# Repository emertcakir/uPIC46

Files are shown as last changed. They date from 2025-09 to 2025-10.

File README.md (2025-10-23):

# uPIC46
EMC

uPIC46 Development Board

The uPIC46 is a development board designed around the Microchip PIC18F46K22-I/PT microcontroller.  
It is intended for hobbyists, students, and professionals who want a versatile platform for learning, prototyping, and industrial communication testing.

----------------------------------------------------
✨ Features
----------------------------------------------------
- MCU: PIC18F46K22-I/PT (TQFP package)
- Clocking: External crystal oscillator support
- Memory Expansion: Onboard 24LC256 I²C EEPROM
- RTC: DS3231MZ real-time clock
- USB-UART Bridge: For programming and PC communication
- Connectivity:
  * UART, SPI, I²C headers exposed
  * RTS/CTS and other flow-control pins available on headers
  * RS-485 transceiver for half-duplex communication
  * CAN Bus interface via MCP2515 + SN65HVD230
- Reset & Indicators:
  * Reset push button
  * User indicator LEDs
- Headers:
  * Clearly labeled header pins (A1, A2, A3…) with silkscreen reference table on PCB
  * Breakout headers for easy access to MCU I/O pins

----------------------------------------------------
🛠 Hardware Design
----------------------------------------------------
- Compact and user-friendly layout
- Industrial interfaces: CAN and RS-485 included
- Silkscreen pinout table on PCB for quick reference
----------------------------------------------------
📸 Images
----------------------------------------------------
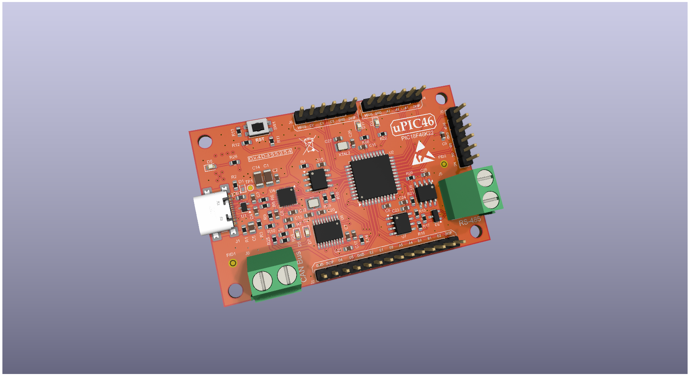
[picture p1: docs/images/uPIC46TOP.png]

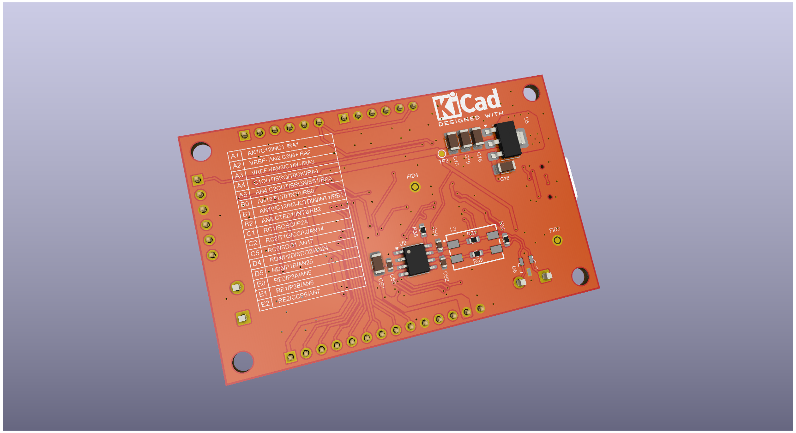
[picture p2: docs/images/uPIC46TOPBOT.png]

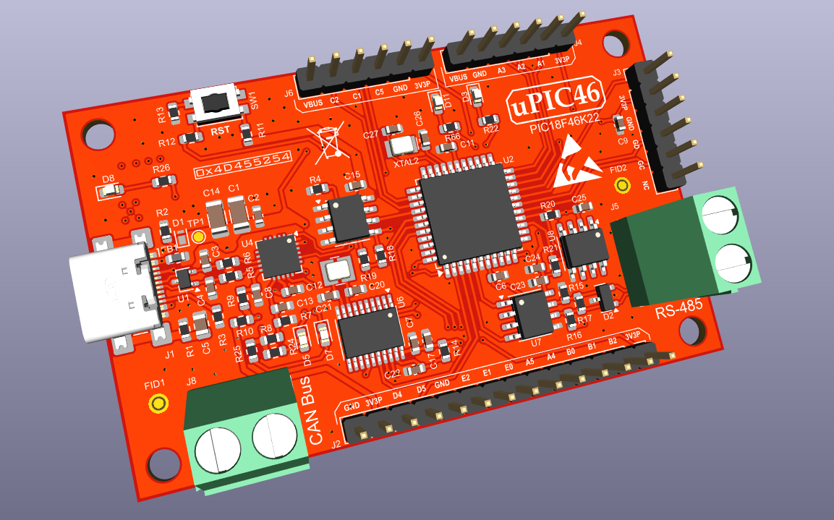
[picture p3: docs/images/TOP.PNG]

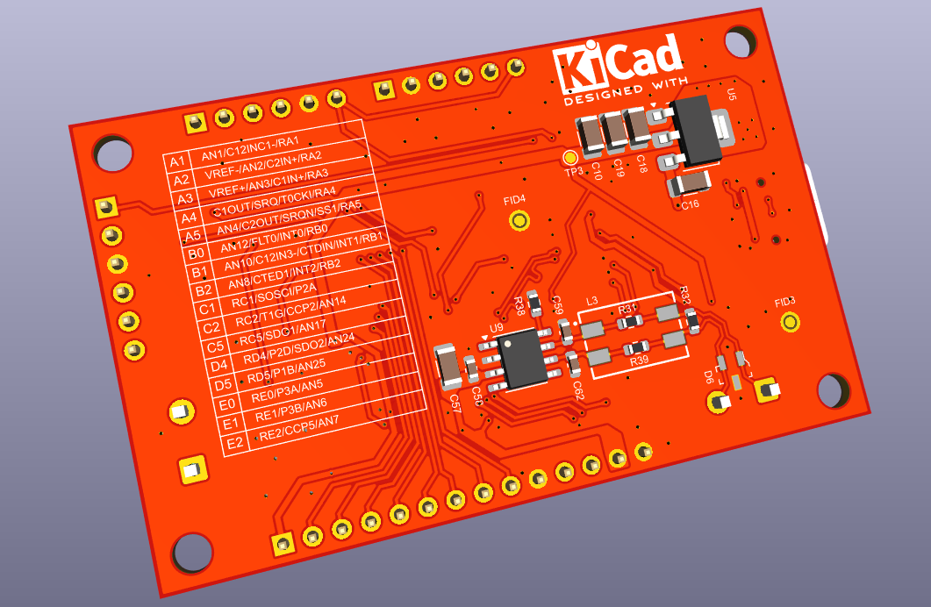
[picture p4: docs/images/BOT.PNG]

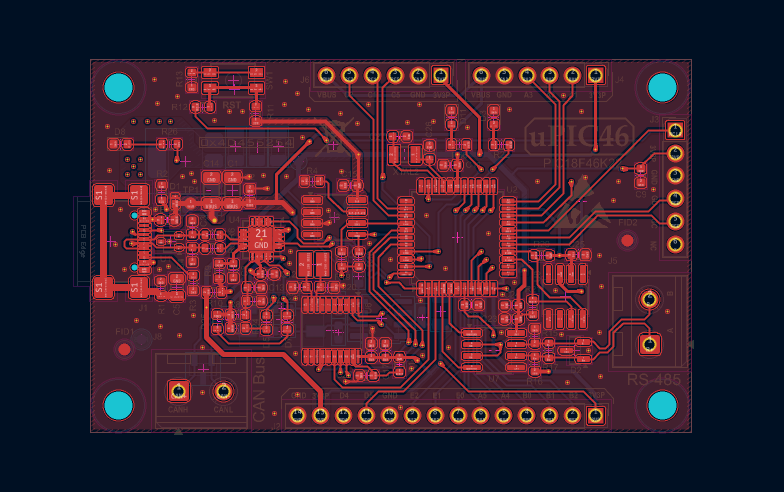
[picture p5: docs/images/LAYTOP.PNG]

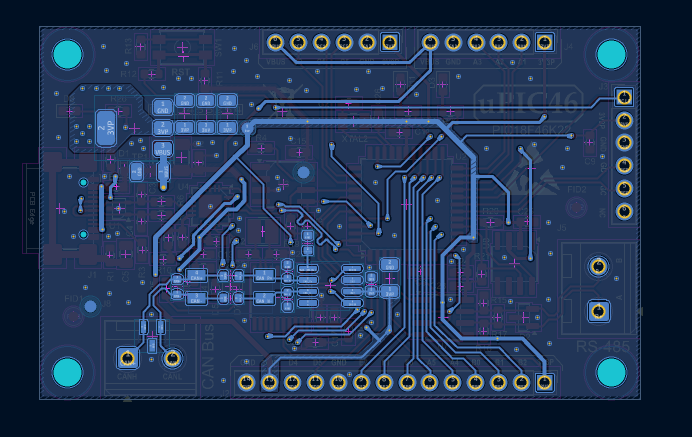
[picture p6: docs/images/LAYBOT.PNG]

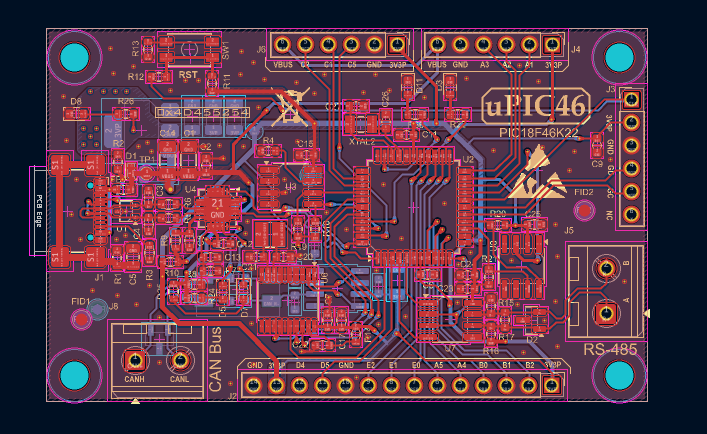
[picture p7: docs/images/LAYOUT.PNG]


----------------------------------------------------
📜 License
----------------------------------------------------
This project is open-source. You are free to use, modify, and distribute it under the terms of the MIT License.

CRITICAL WARNING: This PCB design is currently an experimental, unverified prototype (AS-IS). I have not yet manufactured or functionally tested this version. Proceeding with production carries a high risk of failure and is undertaken solely at your own risk.

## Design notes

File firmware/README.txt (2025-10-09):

uPIC46 Example Firmware Collection

This archive contains simple example projects for the uPIC46 development board (PIC18F46K22).
Each example is self-contained (single-file main.c) and intended to be imported into MPLAB X (XC8).
Adjust configuration bits in MPLAB X Project -> Configuration Bits before programming the device.

Assumptions used in the examples:
- MCU clock: external 8 MHz crystal (update _XTAL_FREQ if different)
- LED1 -> RC0
- LED2 -> RD3
- UART1 TX -> RC6 (EUSART TX)
- UART1 RX -> RC7 (EUSART RX)
- I2C (bit-banged) SDA -> RB4, SCL -> RB5
- SPI (bit-banged for MCP2515) SCK -> RD0, MOSI -> RD4, MISO -> RD1, CS -> RD2
- RS485 DE (if used) -> RB3

These examples are for demonstration and testing; they are not production-ready drivers.

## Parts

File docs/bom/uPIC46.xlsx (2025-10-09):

 |  | uPIC46 Development Board
Reference | Qty | Value | MPN | Footprint | Description
C1,C10,C19 | 3 | - | CGA5L2X7R1E105K160AA | Capacitor_SMD:C_1206_3216Metric | Unpolarized capacitor
C2,C6,C7,C8,C9,C11,C12,C15,C17,C22,C23,C24,C25,C58 | 14 | - | CC0603KRX7R8BB104 | Capacitor_SMD:C_0603_1608Metric | Unpolarized capacitor
C3,C4 | 2 | - | 0603YC470KAT2A | Capacitor_SMD:C_0603_1608Metric | Unpolarized capacitor
C5 | 1 | - | CC0805KRX7R9BB222 | Capacitor_SMD:C_0805_2012Metric | Unpolarized capacitor
C13 | 1 | - | KGM15AR51E103KT | Capacitor_SMD:C_0603_1608Metric | Unpolarized capacitor
C14 | 1 | - | CL31B475KAHNFNE | Capacitor_SMD:C_1206_3216Metric | Unpolarized capacitor
C16,C18,C57 | 3 | - | CL31B106KAHNNNE | Capacitor_SMD:C_1206_3216Metric | Unpolarized capacitor
C20,C21,C26,C27 | 4 | - | CC0603KRNPO9BN120 | Capacitor_SMD:C_0603_1608Metric | Unpolarized capacitor
C59,C62 | 2 | - | KGM15AR71E101MT | Capacitor_SMD:C_0603_1608Metric | Unpolarized capacitor
D1 | 1 | - | PTVS5V0Z1USKYL | Diode_SMD:Nexperia_DSN1608-2_1.6x0.8mm | 5V, 1200W TVS unidirectional diode, DSN1608-2
D2 | 1 | - | SM712-02HTG | Package_TO_SOT_SMD:SOT-23 | 7V/12V, 600W Asymmetrical TVS Diode Array, SOT-23
D3,D5,D7,D8,D11 | 5 | - | 150060RS75000 | LED_SMD:LED_0603_1608Metric | Light emitting diode
D6 | 1 | - | PESD1CAN,215 | digikey-footprints:SOT-23-3 | TVS DIODE 24V 70V SOT23
FB1 | 1 | - | BLM18AG601BH1D | Inductor_SMD:L_0603_1608Metric | Ferrite bead
J1 | 1 | - | USB4110-GF-A | Connector_USB:USB_C_Receptacle_GCT_USB4110 | USB 2.0-only 16P Type-C Receptacle connector
J2 | 1 | Conn_01x14_Socket | HEADER | Connector_PinHeader_2.54mm:PinHeader_1x14_P2.54mm_Vertical | Generic connector, single row, 01x14, script generated
J3 | 1 | Conn_PIC_ICSP_ICD | HEADER | Connector_PinHeader_2.54mm:PinHeader_1x06_P2.54mm_Vertical | Microchip PIC In-Circuit Serial Programming/Debugging (ICSP/ICD) connector
J4,J6 | 2 | Conn_01x06_Socket | HEADER | Connector_PinHeader_2.54mm:PinHeader_1x06_P2.54mm_Vertical | Generic connector, single row, 01x06, script generated
J5,J8 | 2 | - | RND 205-00045 | TerminalBlock_RND:TerminalBlock_RND_205-00045_1x02_P5.00mm_Horizontal | Generic screw terminal, single row, 01x02, script generated (kicad-library-utils/schlib/autogen/connector/)
R1,R12 | 2 | - | ERJ-3EKF1000V | Resistor_SMD:R_0603_1608Metric | Resistor
R2,R3,R4 | 3 | - | RC0603FR-075K1L | Resistor_SMD:R_0603_1608Metric | Resistor
R5,R6,R9,R10,R13,R31,R38,R39 | 8 | - | RC0603JR-070RL | Resistor_SMD:R_0603_1608Metric | Resistor
R7 | 1 | - | ERA-3AEB153V | Resistor_SMD:R_0603_1608Metric | Resistor
R8,R11,R14,R15,R16,R18,R19,R20,R21 | 9 | - | RC0603FR-0710KL | Resistor_SMD:R_0603_1608Metric | Resistor
R17,R32 | 2 | - | ERA-3AEB121V | Resistor_SMD:R_0603_1608Metric | Resistor
R22,R24,R25,R26,R66 | 5 | - | ERA-3AEB102V | Resistor_SMD:R_0603_1608Metric | Resistor
SW1 | 1 | - | EVQ-P2202W | Button_Switch_SMD:SW_SPST_EVQP2 | Push button switch, generic, two pins
U1 | 1 | - | TPD2E2U06DCK | Package_TO_SOT_SMD:SOT-323_SC-70 | Dual-Channel High-Speed ESD Protection, SC-70
U2 | 1 | - | PIC18F46K22-I/PT | Package_QFP:TQFP-44_10x10mm_P0.8mm | 64K Flash, 3.5K RAM, 1K EEPROM PIC18 Microcontroller ADC PWM SPI I2C USART in TQFP44 package
U3 | 1 | - | 24LC256 | Package_SO:SOIC-8_3.9x4.9mm_P1.27mm | I2C Serial EEPROM, 256Kb, DIP-8/SOIC-8/TSSOP-8/DFN-8
U4 | 1 | - | FT231XQ-R | Package_DFN_QFN:QFN-20-1EP_4x4mm_P0.5mm_EP2.5x2.5mm | Full Speed USB to Full Handshake UART, QFN-20
U5 | 1 | - | AMS1117-3.3 | Package_TO_SOT_SMD:SOT-223-3_TabPin2 | 1A Low Dropout regulator, positive, 3.3V fixed output, SOT-223
U6 | 1 | - | MCP2515-Xst | Package_SO:TSSOP-20_4.4x6.5mm_P0.65mm | Stand-Alone CAN Controller with SPI Interface, TSSOP-20
U7 | 1 | - | MAX3485CSA+T | Package_SO:SOIC-8_3.9x4.9mm_P1.27mm | True RS-485/RS-422, 10Mbps, Slew-Rate Limited, with low-power shutdown, with receiver/driver enable, 32 receiver drive capacitity, DIP-8 and SOIC-8
U8 | 1 | - | DS3231MZ | Package_SO:SOIC-8_3.9x4.9mm_P1.27mm | Â±5ppm, I2C Real-Time Clock SOIC-8
U9 | 1 | - | SN65HVD230 | Package_SO:SOIC-8_3.9x4.9mm_P1.27mm | CAN Bus Transceivers, 3.3V, 1Mbps, Low-Power capabilities, SOIC-8
XTAL1 | 1 | - | NX3225GD-8MHZ-STD-CRA-3 | digikey-footprints:SMD-2_3.2x2.5mm | CRYSTAL 8.0000MHZ 8PF SMD
XTAL2 | 1 | - | ECS-.327-12.5-34B-TR | digikey-footprints:SMD-2_3.2x1.5mm | CRYSTAL 32.7680KHZ 12.5PF SMD

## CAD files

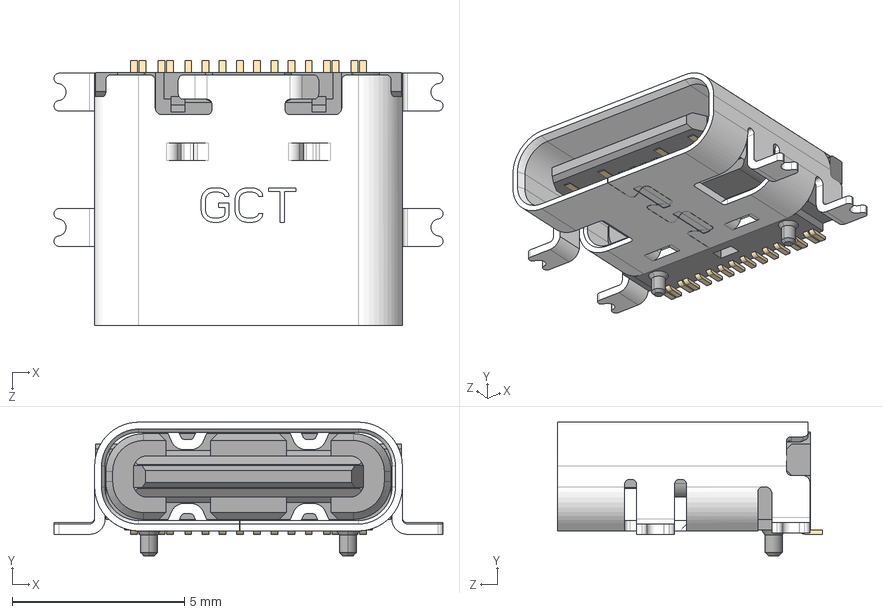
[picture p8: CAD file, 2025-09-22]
hardware/3D/USB4110GFA--3DModel-STEP-269445.STEP
11.3 x 3.89 x 7.70 mm

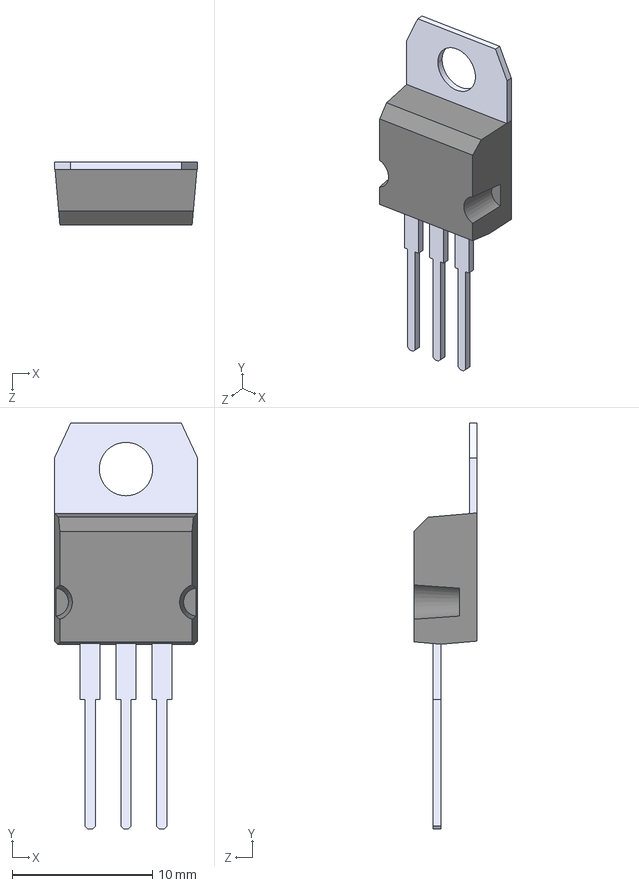
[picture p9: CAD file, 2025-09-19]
hardware/3D/L7805CV.STEP
10.2 x 28.9 x 4.50 mm

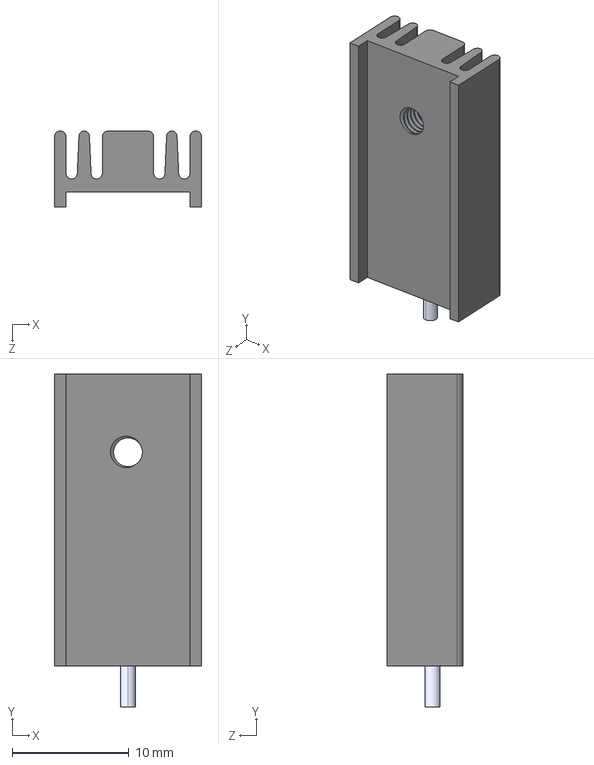
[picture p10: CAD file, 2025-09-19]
hardware/3D/SK 95 25 STS TO 220--3DModel-STEP-269445.STEP
12.6 x 28.5 x 6.50 mm

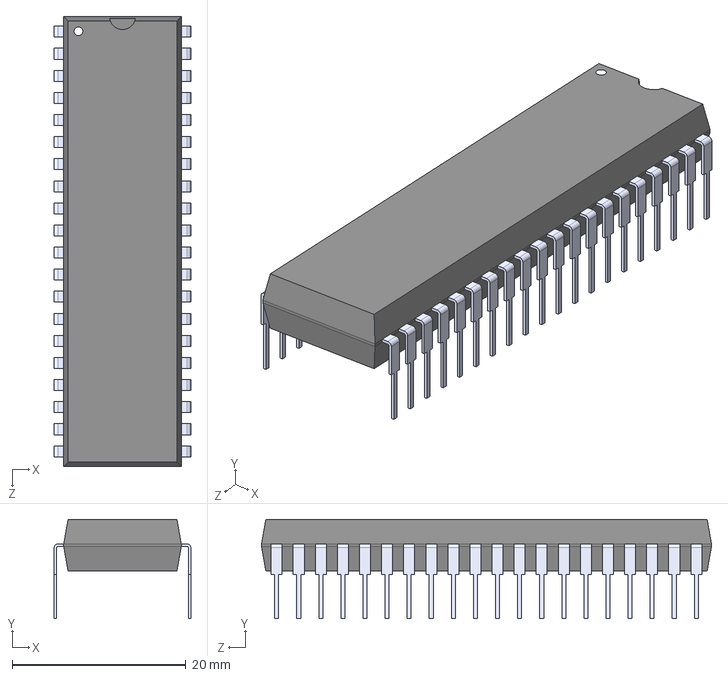
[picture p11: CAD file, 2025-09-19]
hardware/3D/PIC18F46K22-I_P.step
15.7 x 11.4 x 51.8 mm

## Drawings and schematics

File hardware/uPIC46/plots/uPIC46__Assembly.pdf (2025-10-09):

B.Paste F.Cu | | | 1.51 mm | 1 B.Cu

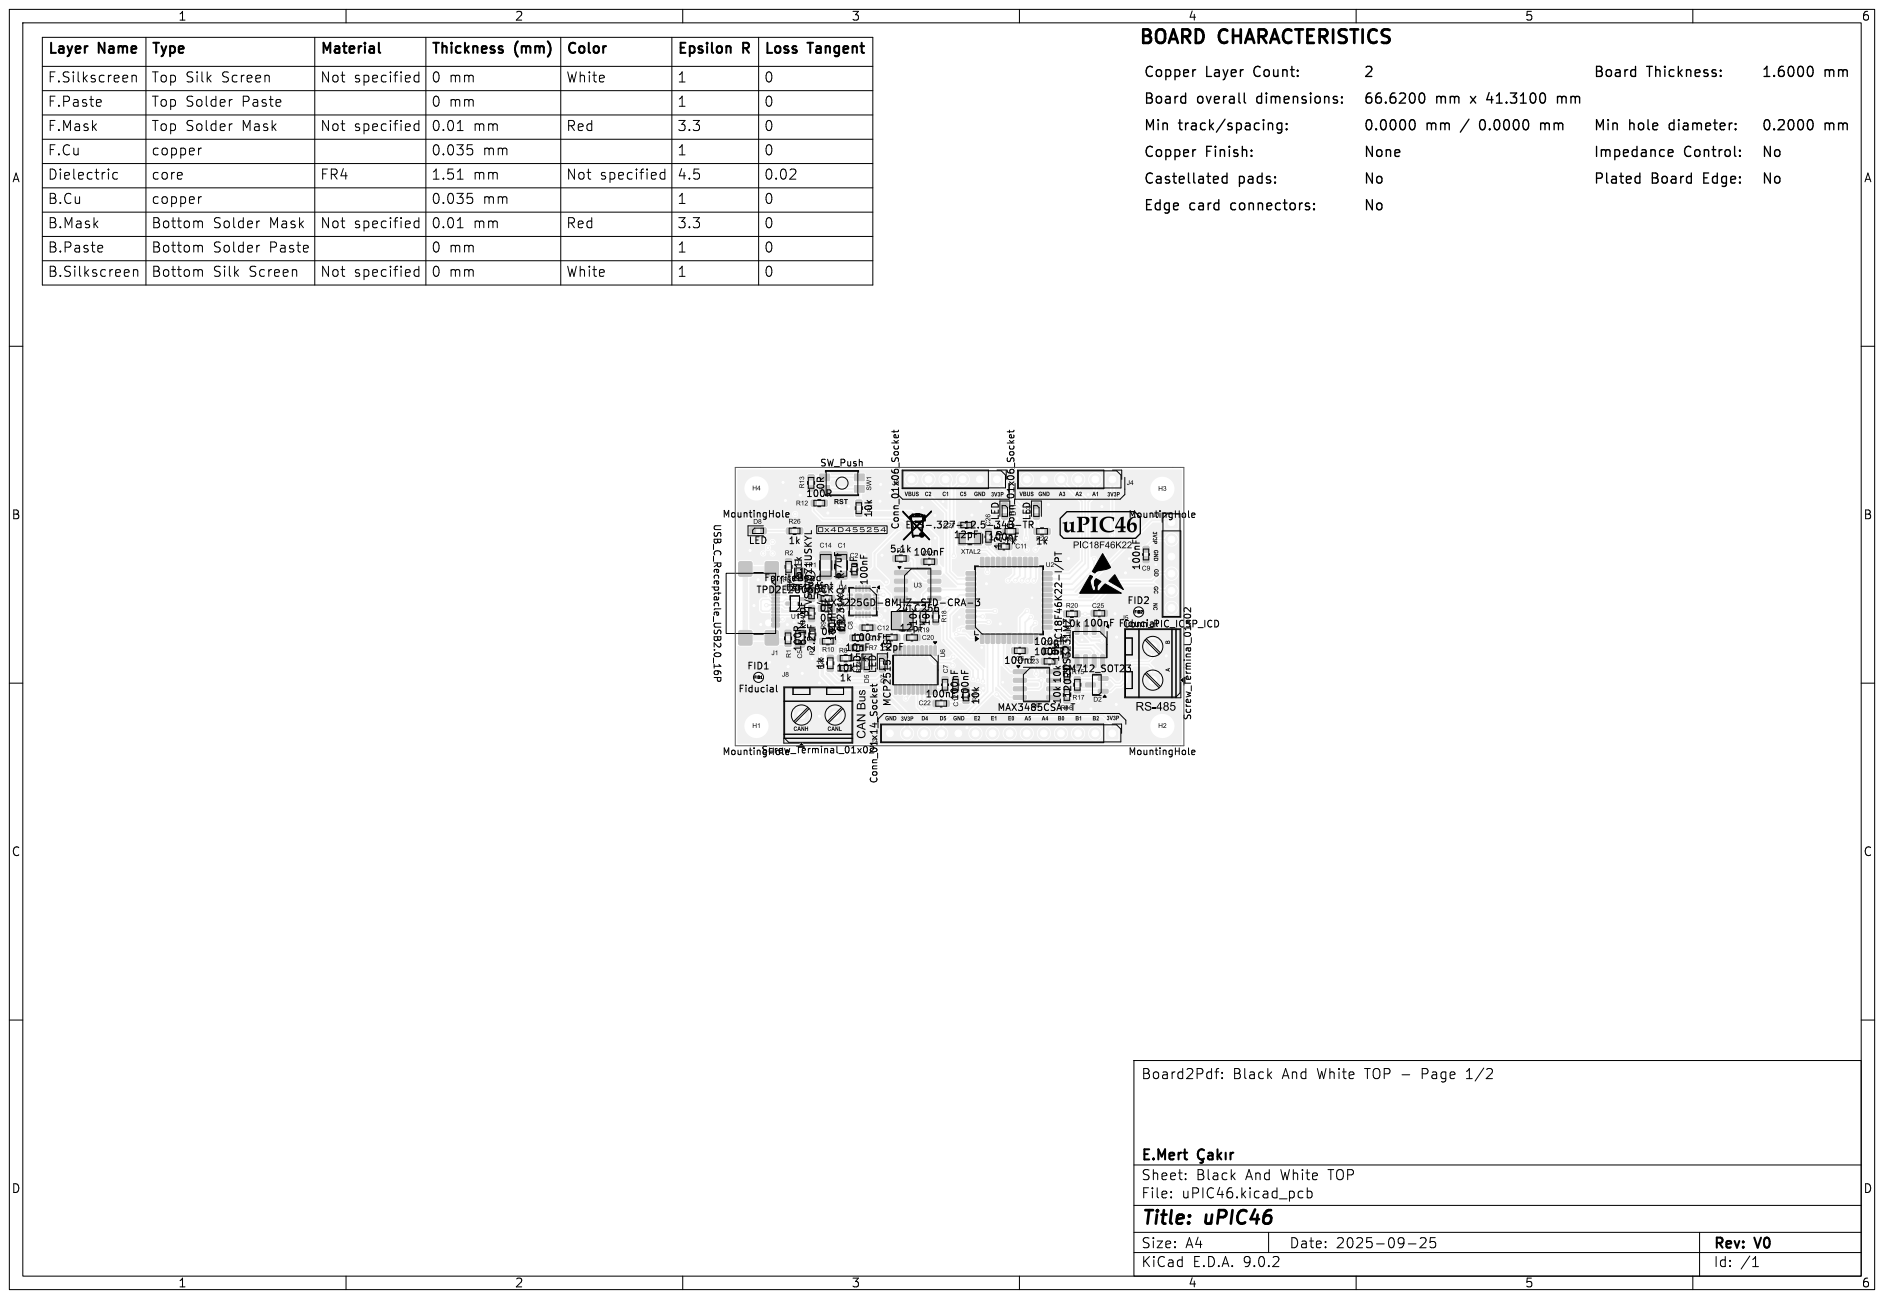
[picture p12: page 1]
FID1; FID2; D Date: 2025-09-25 KiCad; E.D.A. 9.0.2 Size: A4; Rev: V0; Id: /1 Title: uPIC46; File: uPIC46.kicad_pcb Sheet: Black; And; White; TOP; E.Mert þÿÇak1r Board2Pdf:; Black; TOP -; Page; Copper; Finish: 1; 1 Red; Plated; Board; Edge: copper; Thickness: 0 Top Solder Paste; Castellated; pads: 0 mm; Impedance; Control: Edge card; connectors:; Board overall; dimensions: Top Silk Screen; Not specified; Min track/spacing:; Loss Tangent F.Silkscreen; Bottom Solder Mask; core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

(mm) 0 mm | Not specified Thickness White | 1 | Copper Layer Count: F.Paste

Layer Name B.Silkscreen | Top Solder Mask | Material | 0 mm 0.01 mm | 0 Type F.Mask 0 Bottom Solder Paste 0

Epsilon R

0 Not specified

No Not specified

Screen | FR4 | 0.035 mm | 1 B.Mask Dielectric | 0.02 Bottom Silk

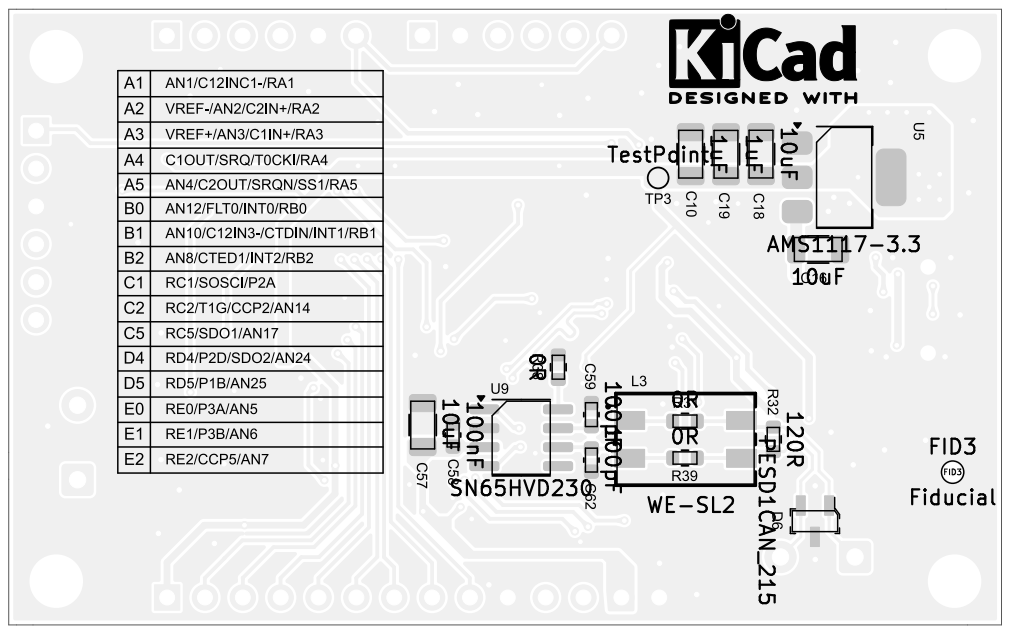
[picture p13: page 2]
FID3; D Date: 2025-09-25 KiCad; E.D.A. 9.0.2 Size: A4; Rev: V0; Id: /1 Title: uPIC46; File: uPIC46.kicad_pcb Sheet: Black; And; White; BOT E.Mert þÿÇak1r Board2Pdf:; Black; BOT -; Page 2/2; Fiducial FID3 WE-SL2 ¹⁰uF; 10uF 1uFTestPoint; SN65HVD230; AMS1117-3.3 ¹uF PESD1CAN_215 0R

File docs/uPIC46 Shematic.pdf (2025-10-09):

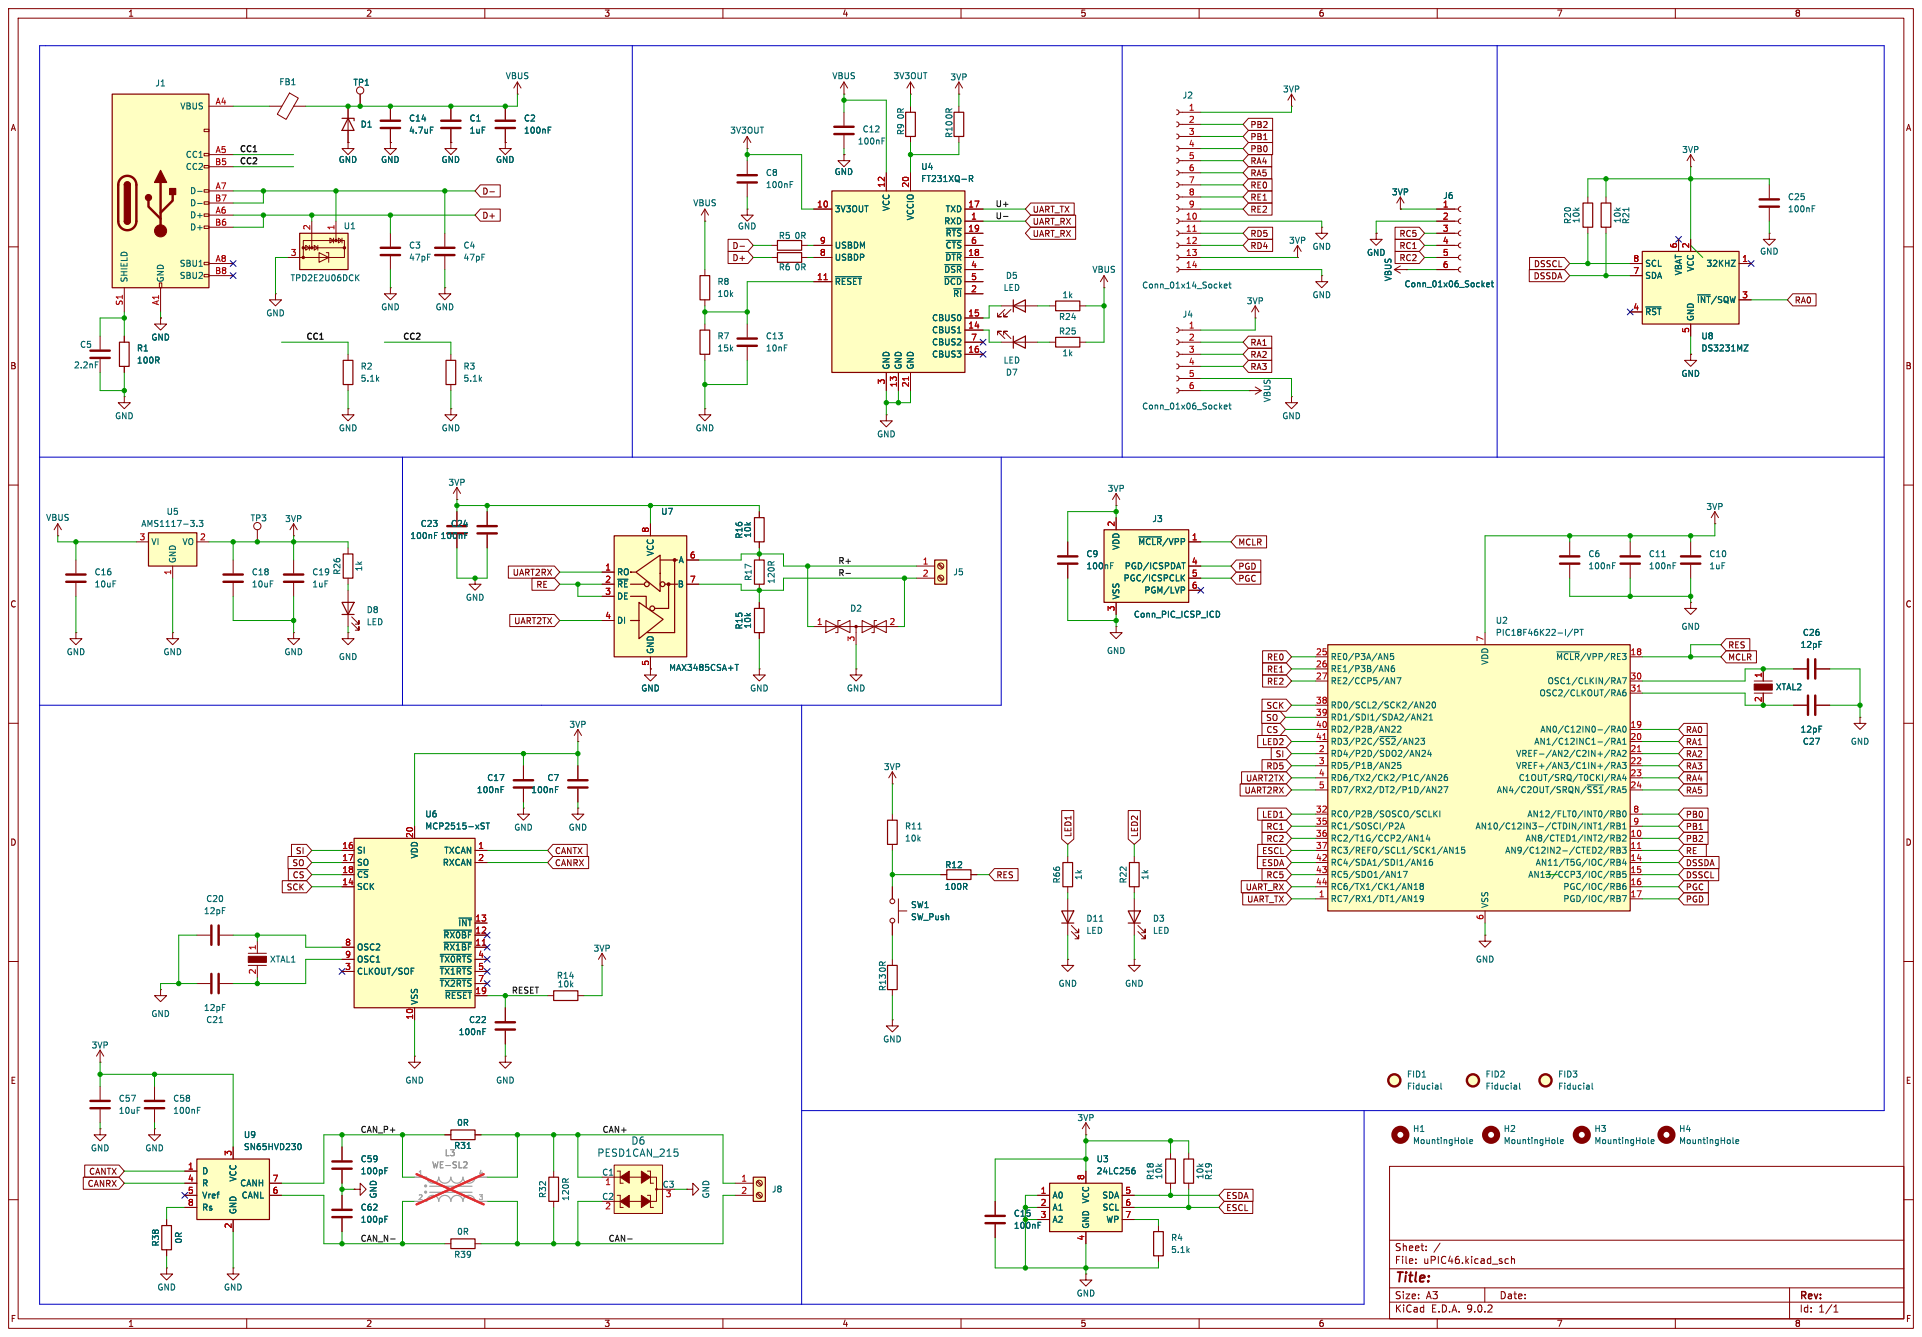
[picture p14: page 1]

3 GND 13 VCCIO 20 GND 21 TXD 17 RXD 1 ~{RTS}19 ~{CTS}6 ~{DTR}18 ~{DSR}4 ~{DCD}5 ~{RI}2 CBUS0 15 CBUS1 14 CBUS2 7 CBUS3 16 U4 FT231XQ-R GND

3 GND 13 VCCIO 20 GND 21 TXD 17 RXD 1 ~{RTS}19 ~{CTS}6 ~{DTR}18 ~{DSR}4 ~{DCD}5 ~{RI}2 CBUS0 15 CBUS1 14 CBUS2 7 CBUS3 16 GND

3 ~{MCLR}/VPP1 PGD/ICSPDAT 4 PGC/ICSPCLK 5 PGM/LVP 6 R12

3 ~{MCLR}/VPP1 PGD/ICSPDAT 4 PGC/ICSPCLK 5 PGM/LVP 6

6 ~{MCLR}/VPP/RE3 18 OSC1/CLKIN/RA7 30 OSC2/CLKOUT/RA6 31 AN0/C12IN0-/RA0 19 AN1/C12INC1-/RA1 20 VREF-/AN2/C2IN+/RA2 21 VREF+/AN3/C1IN+/RA3 22 C1OUT/SRQ/T0CKI/RA4 23 AN4/C2OUT/SRQN/~{SS1}/RA5 24 AN12/FLT0/INT0/RB0 8 AN10/C12IN3-/CTDIN/INT1/RB1 9 AN8/CTED1/INT2/RB2 10 AN9/C12IN2-/CTED2/RB3 11 AN11/T5G/IOC/RB4 14 AN13/CCP3/IOC/RB5 15 PGC/IOC/RB6 16 PGD/IOC/RB7 17 U2PIC18F46K22-I/PT

2 CANH 7 CANL 6 U6 MCP2515-xST SI 16 SO 17 ~{CS} 18 SCK 14 OSC2 8 OSC1 9 CLKOUT/SOF 3 VDD 20 VSS 10 TXCAN 1 RXCAN 2 ~{INT} 13 ~{RX0BF}12 ~{RX1BF}11 ~{TX0RTS}4 ~{TX1RTS}5 ~{TX2RTS}7 ~{RESET} 19 C17

Id: 1/1 Title: File: uPIC46.kicad_sch Sheet: /

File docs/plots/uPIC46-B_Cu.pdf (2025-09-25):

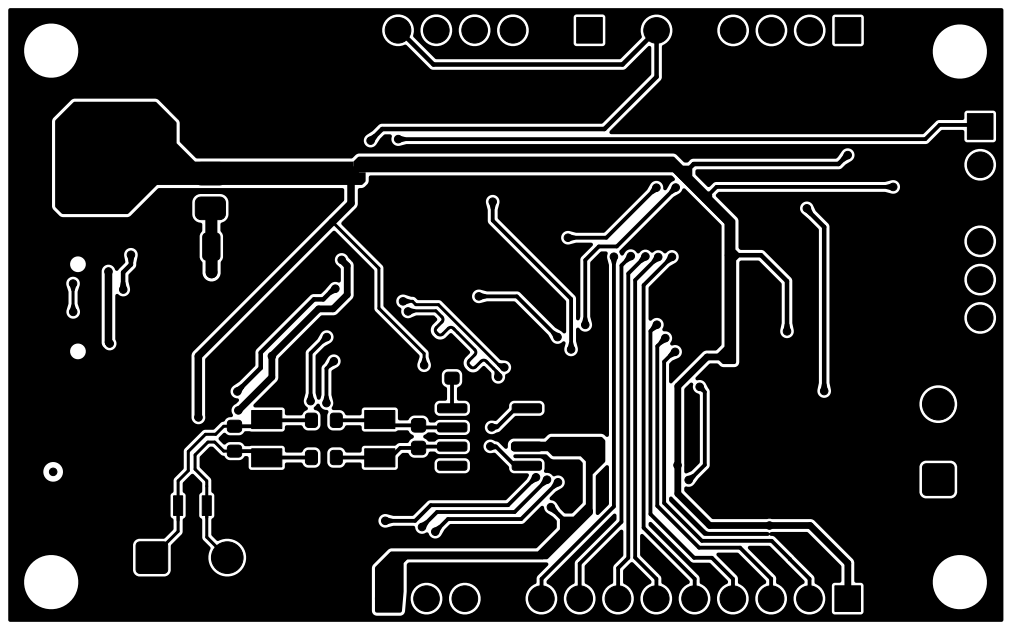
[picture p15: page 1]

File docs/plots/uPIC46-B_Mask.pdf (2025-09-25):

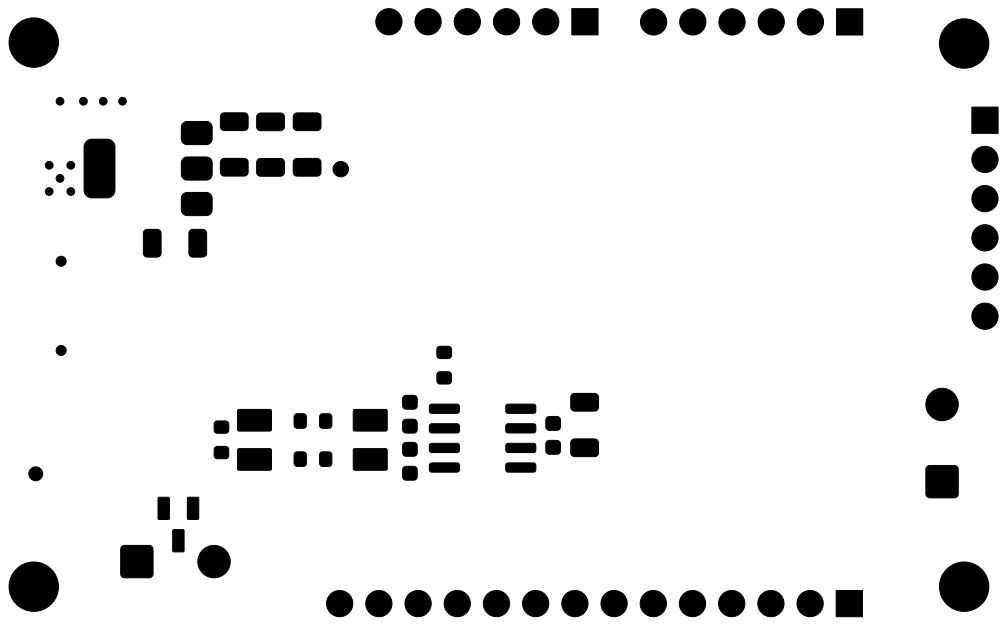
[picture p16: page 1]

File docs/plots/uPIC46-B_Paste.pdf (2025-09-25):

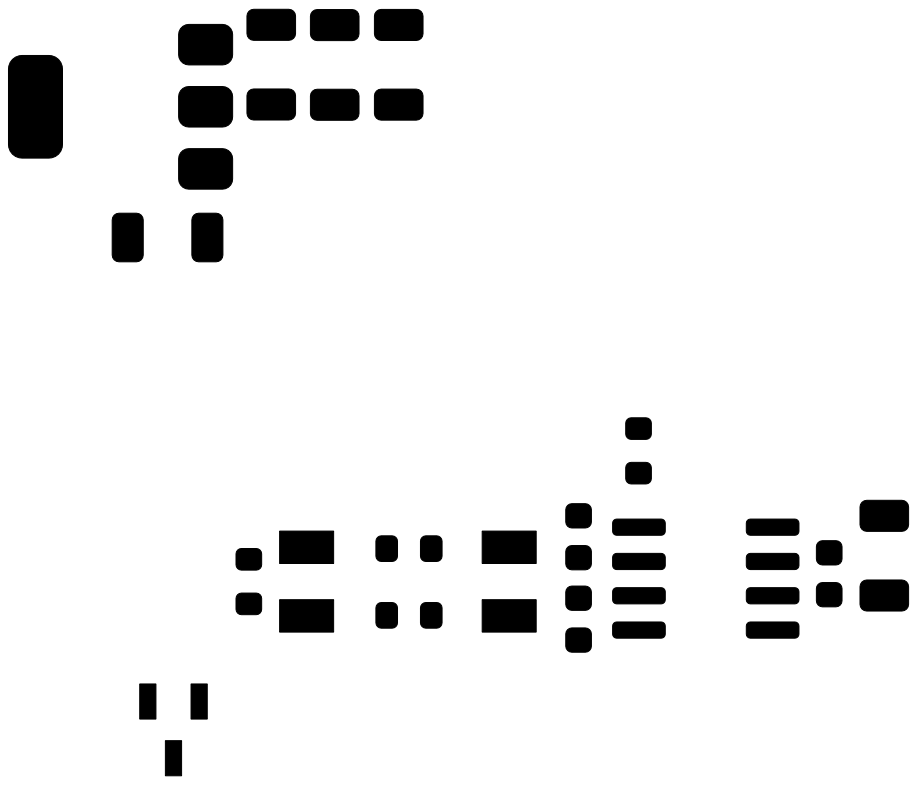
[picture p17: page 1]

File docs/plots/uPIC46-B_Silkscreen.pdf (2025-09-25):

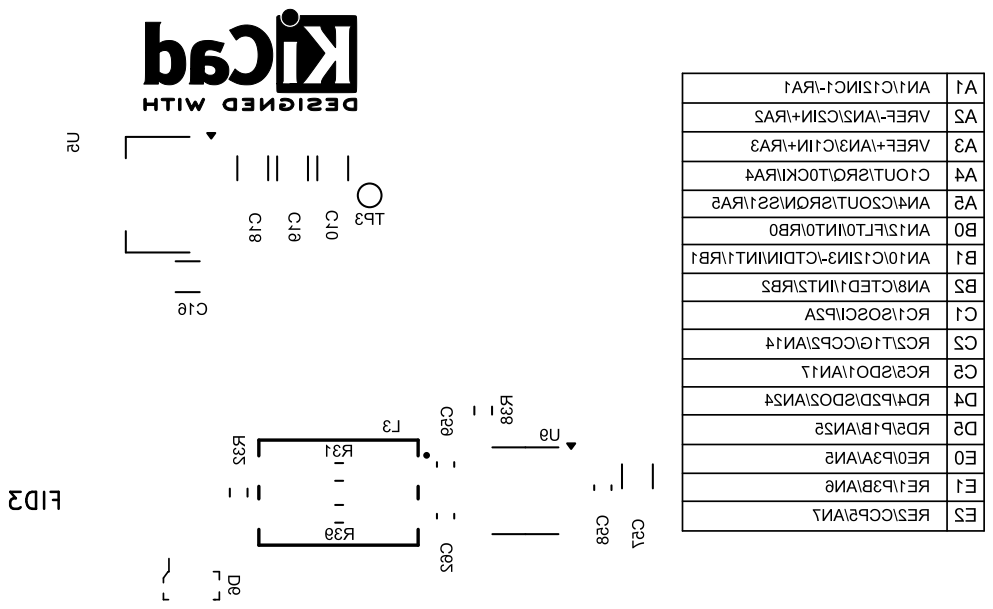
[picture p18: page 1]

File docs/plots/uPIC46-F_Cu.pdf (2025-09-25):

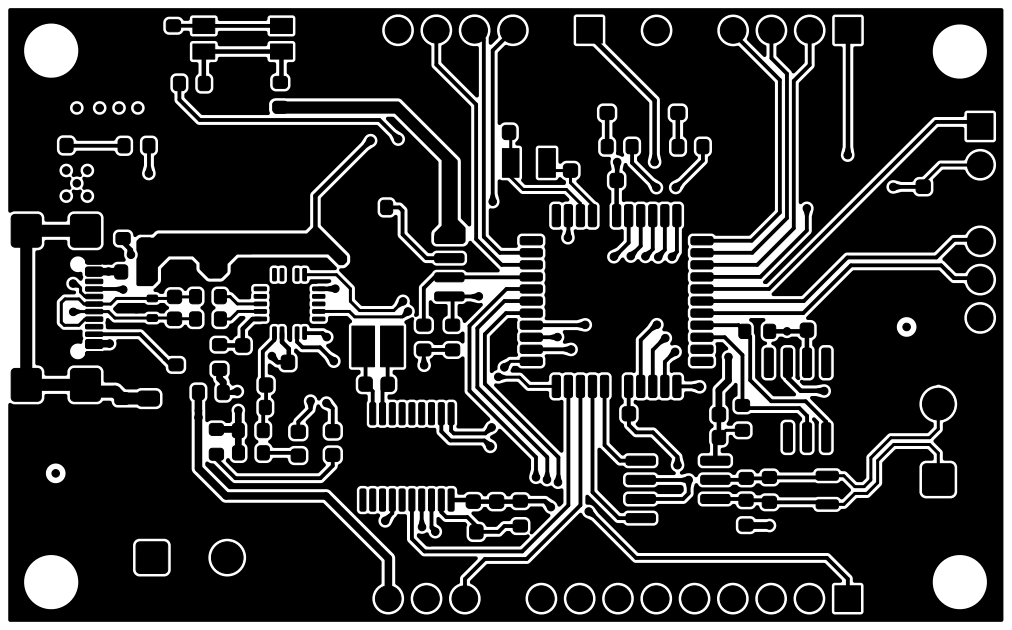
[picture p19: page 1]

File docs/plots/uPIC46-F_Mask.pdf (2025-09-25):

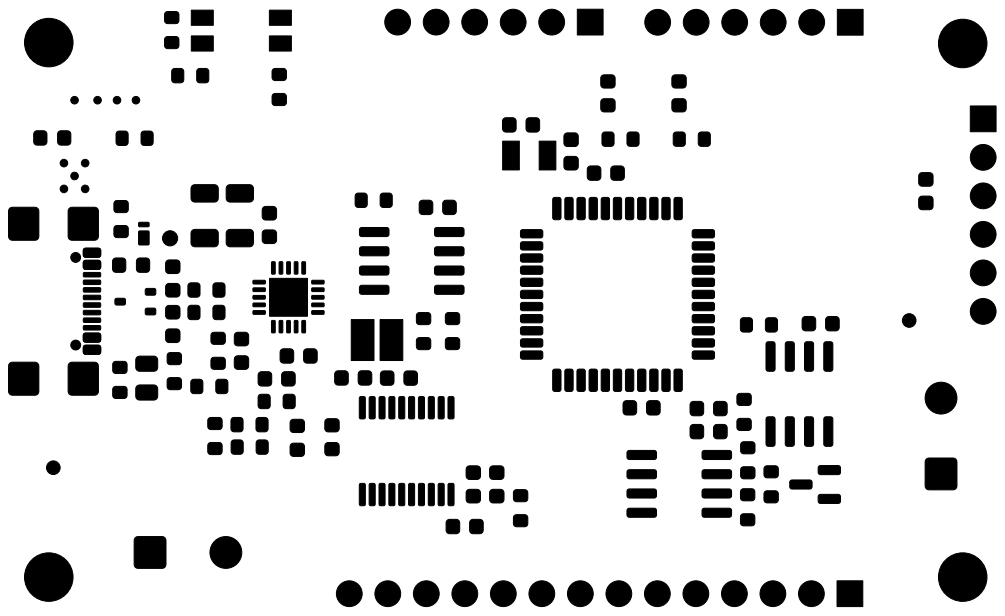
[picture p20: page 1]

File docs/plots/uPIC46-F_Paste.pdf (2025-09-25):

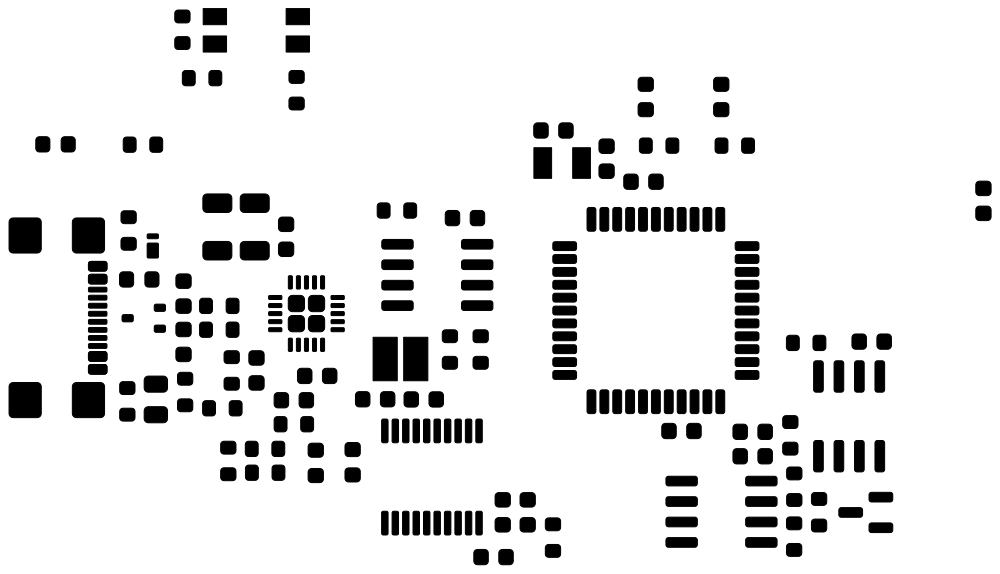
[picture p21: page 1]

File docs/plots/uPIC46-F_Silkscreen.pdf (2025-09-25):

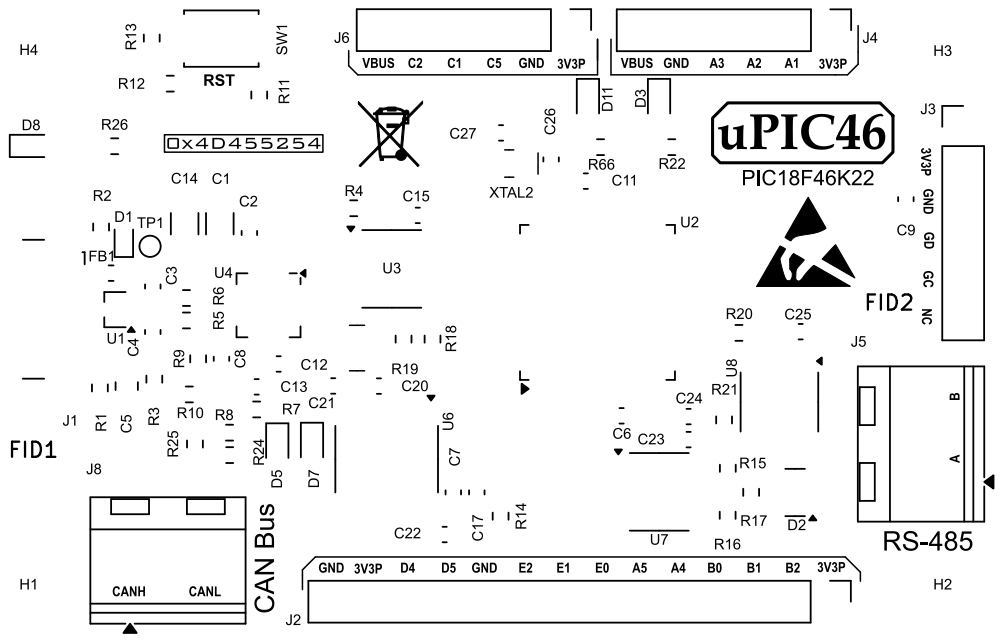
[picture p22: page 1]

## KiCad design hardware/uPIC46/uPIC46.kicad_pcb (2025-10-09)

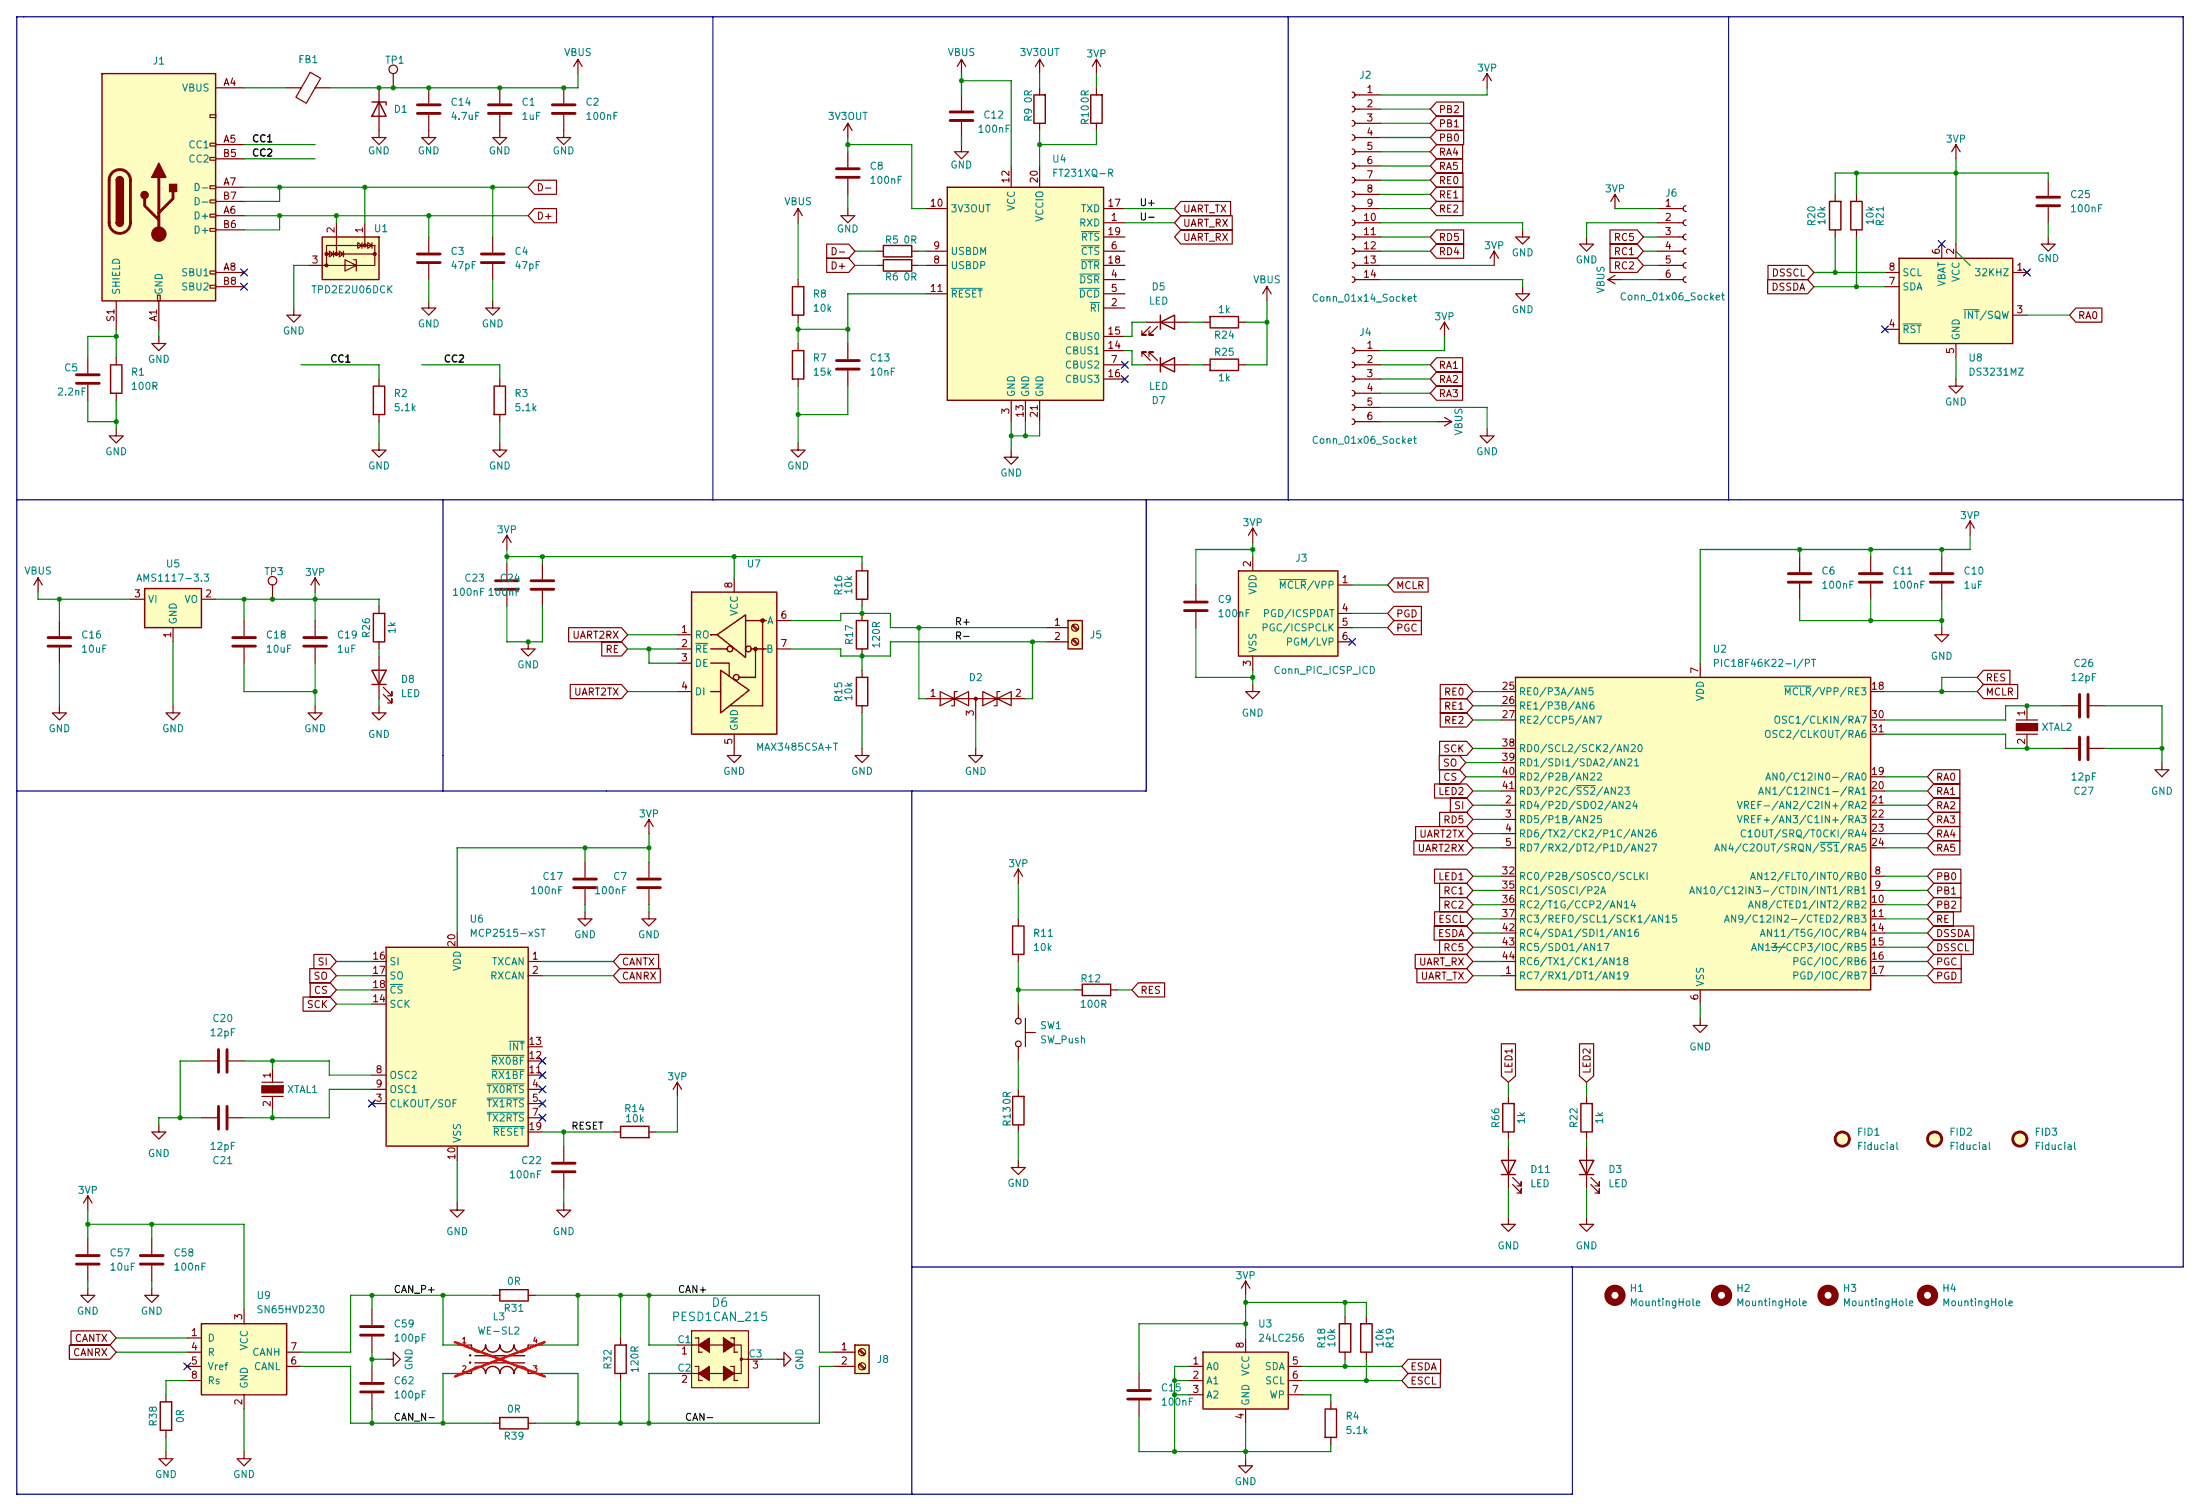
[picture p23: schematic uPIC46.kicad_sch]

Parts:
C1, C10, C19: 1uF; C_1206_3216Metric
C2, C6, C7, C8, C9, C11, C12, C15, C17, C22, C23, C24, C25, C58: 100nF; C_0603_1608Metric
C3, C4: 47pF; C_0603_1608Metric
C5: 2.2nF; C_0805_2012Metric
C13: 10nF; C_0603_1608Metric
C14: 4.7uF; C_1206_3216Metric
C16, C18, C57: 10uF; C_1206_3216Metric
C20, C21, C26, C27: 12pF; C_0603_1608Metric
C59, C62: 100pF; C_0603_1608Metric
D1: PTVS5V0Z1USKYL; Nexperia_DSN1608-2_1.6x0.8mm
D2: SM712_SOT23; SOT-23
D3, D5, D7, D8, D11: LED; LED_0603_1608Metric
D6: PESD1CAN_215; SOT-23-3; MPN PESD1CAN,215; Digi-Key_PN 1727-3817-1-ND
FB1: FerriteBead; L_0603_1608Metric
FID1, FID2, FID3: Fiducial; Fiducial_0.5mm_Mask1.5mm
H1, H2, H3, H4: MountingHole; MountingHole_3.2mm_M3_ISO7380
J1: USB_C_Receptacle_USB2.0_16P; USB_C_Receptacle_GCT_USB4110
J2: Conn_01x14_Socket; PinHeader_1x14_P2.54mm_Vertical
J3: Conn_PIC_ICSP_ICD; PinHeader_1x06_P2.54mm_Vertical
J4, J6: Conn_01x06_Socket; PinHeader_1x06_P2.54mm_Vertical
J5, J8: Screw_Terminal_01x02; TerminalBlock_RND_205-00045_1x02_P5.00mm_Horizontal
L3: WE-SL2; not fitted
R1, R12: 100R; R_0603_1608Metric
R2, R3, R4: 5.1k; R_0603_1608Metric
R5, R6, R9, R10, R13, R31, R38, R39: 0R; R_0603_1608Metric
R7: 15k; R_0603_1608Metric
R8, R11, R14, R15, R16, R18, R19, R20, R21: 10k; R_0603_1608Metric
R17, R32: 120R; R_0603_1608Metric
R22, R24, R25, R26, R66: 1k; R_0603_1608Metric
SW1: SW_Push; SW_SPST_EVQP2
TP1, TP3: TestPoint; TestPoint_Pad_D1.0mm
U1: TPD2E2U06DCK; SOT-323_SC-70
U2: PIC18F46K22-I/PT; TQFP-44_10x10mm_P0.8mm
U3: 24LC256; SOIC-8_3.9x4.9mm_P1.27mm
U4: FT231XQ-R; QFN-20-1EP_4x4mm_P0.5mm_EP2.5x2.5mm
U5: AMS1117-3.3; SOT-223-3_TabPin2
U6: MCP2515-xST; TSSOP-20_4.4x6.5mm_P0.65mm
U7: MAX3485CSA+T; SOIC-8_3.9x4.9mm_P1.27mm
U8: DS3231MZ; SOIC-8_3.9x4.9mm_P1.27mm
U9: SN65HVD230; SOIC-8_3.9x4.9mm_P1.27mm
XTAL1: NX3225GD-8MHZ-STD-CRA-3; SMD-2_3.2x2.5mm; MPN NX3225GD-8MHZ-STD-CRA-3; Digi-Key_PN 644-1178-1-ND
XTAL2: ECS-.327-12.5-34B-TR; SMD-2_3.2x1.5mm; MPN ECS-.327-12.5-34B-TR; Digi-Key_PN XC1617CT-ND

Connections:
3V3OUT: C8.1, R9.2, U4.10 (3V3OUT)
3VP: C6.1, C7.1, C9.1, C10.1, C11.1, C15.1, C17.1, C18.1, C19.1, C23.1, C24.1, C25.1, C57.1, C58.1, J2.1, J2.13, J3.2 (VDD), J4.1, J6.1, R10.2, R11.1, R14.2, R16.2, R18.2, R19.2, R20.2, R21.2, R26.2, TP3.1, U2.7 (VDD), U2.28 (VDD), U3.8 (VCC), U5.2 (VO), U6.20 (VDD), U7.8 (VCC), U8.2 (VCC), U9.3 (VCC)
/CAN+: D6.1 (C1), J8.1, L3.4, R31.1, R32.2
/CAN-: D6.2 (C2), J8.2, L3.3, R32.1, R39.1
/CAN_N-: C62.2, L3.2, R39.2, U9.6 (CANL)
/CAN_P+: C59.1, L3.1, R31.2, U9.7 (CANH)
/CC1: J1.A5 (CC1), R2.1
/CC2: J1.B5 (CC2), R3.1
/R+: D2.1 (A1), J5.1, R16.1, R17.2, U7.6 (A)
/R-: D2.2 (A2), J5.2, R15.2, R17.1, U7.7 (B)
/RESET: C22.1, R14.1, U6.19 (~RESET)
CANRX: U6.2 (RXCAN), U9.4 (R)
CANTX: U6.1 (TXCAN), U9.1 (D)
CS: U2.40 (RD2/P2B/AN22), U6.18 (~CS)
D+: C3.1, J1.A6 (D+), J1.B6 (D+), R6.1, U1.2
D-: C4.1, J1.A7 (D-), J1.B7 (D-), R5.1, U1.1
DSSCL: R20.1, U2.15 (AN13/CCP3/IOC/RB5), U8.8 (SCL)
DSSDA: R21.1, U2.14 (AN11/T5G/IOC/RB4), U8.7 (SDA)
ESCL: R19.1, U2.37 (RC3/REFO/SCL1/SCK1/AN15), U3.6 (SCL)
ESDA: R18.1, U2.42 (RC4/SDA1/SDI1/AN16), U3.5 (SDA)
GND: C1.2, C2.2, C3.2, C4.2, C5.2, C6.2, C7.2, C8.2, C9.2, C10.2, C11.2, C12.2, C13.2, C14.2, C15.2, C16.2, C17.2, C18.2, C19.2, C20.1, C21.1, C22.2, C23.2, C24.2, C25.2, C26.2, C27.2, C57.2, C58.2, C59.2, C62.1, D1.2 (A), D2.3 (common), D3.1 (K), D6.3 (C3), D8.1 (K), D11.1 (K), J1.A1 (GND), J1.A12 (GND), J1.B1 (GND), J1.B12 (GND), J2.10, J2.14, J3.3 (VSS), J4.5, J6.2, R1.2, R2.2, R3.2, R4.2, R7.2, R13.1, R15.1, R38.1, U1.3, U2.6 (VSS), U2.29 (VSS), U3.1 (A0), U3.2 (A1), U3.3 (A2), U3.4 (GND), U4.3 (GND), U4.13 (GND), U4.21 (GND), U5.1 (GND), U6.10 (VSS), U7.5 (GND), U8.5 (GND), U9.2 (GND)
LED1: R66.2, U2.32 (RC0/P2B/SOSCO/SCLKI)
LED2: R22.2, U2.41 (RD3/P2C/~SS2/AN23)
MCLR: J3.1 (~MCLR/VPP), R12.2, U2.18 (~MCLR/VPP/RE3)
unnamed: D3.2 (A), R22.1
unnamed: D5.2 (A), R24.2
unnamed: D5.1 (K), U4.15 (CBUS0)
unnamed: D7.2 (A), R25.2
unnamed: D7.1 (K), U4.14 (CBUS1)
unnamed: D8.2 (A), R26.1
unnamed: D11.2 (A), R66.1
unnamed: FB1.2, J1.A4 (VBUS), J1.A9 (VBUS), J1.B4 (VBUS), J1.B9 (VBUS)
unnamed: C5.1, J1.S1 (SHIELD), R1.1
unnamed: R11.2, R12.1, SW1.1
unnamed: R13.2, SW1.2
unnamed: C26.1, U2.30 (OSC1/CLKIN/RA7), XTAL2.1
unnamed: C27.1, U2.31 (OSC2/CLKOUT/RA6), XTAL2.2
unnamed: R4.1, U3.7 (WP)
unnamed: R5.2, U4.9 (USBDM)
unnamed: R6.2, U4.8 (USBDP)
unnamed: R9.1, R10.1, U4.20 (VCCIO)
unnamed: C13.1, R7.1, R8.2, U4.11 (~RESET)
unnamed: C21.2, U6.9 (OSC1), XTAL1.2
unnamed: C20.2, U6.8 (OSC2), XTAL1.1
unnamed: R38.2, U9.8 (Rs)
PB0: J2.4, U2.8 (AN12/FLT0/INT0/RB0)
PB1: J2.3, U2.9 (AN10/C12IN3-/CTDIN/INT1/RB1)
PB2: J2.2, U2.10 (AN8/CTED1/INT2/RB2)
PGC: J3.5 (PGC/ICSPCLK), U2.16 (PGC/IOC/RB6)
PGD: J3.4 (PGD/ICSPDAT), U2.17 (PGD/IOC/RB7)
RA0: U2.19 (AN0/C12IN0-/RA0), U8.3 (~INT/SQW)
RA1: J4.2, U2.20 (AN1/C12INC1-/RA1)
RA2: J4.3, U2.21 (VREF-/AN2/C2IN+/RA2)
RA3: J4.4, U2.22 (VREF+/AN3/C1IN+/RA3)
RA4: J2.5, U2.23 (C1OUT/SRQ/T0CKI/RA4)
RA5: J2.6, U2.24 (AN4/C2OUT/SRQN/~SS1/RA5)
RC1: J6.4, U2.35 (RC1/SOSCI/P2A)
RC2: J6.5, U2.36 (RC2/T1G/CCP2/AN14)
RC5: J6.3, U2.43 (RC5/SDO1/AN17)
RD4: J2.12
RD5: J2.11, U2.3 (RD5/P1B/AN25)
RE0: J2.7, U2.25 (RE0/P3A/AN5)
RE1: J2.8, U2.26 (RE1/P3B/AN6)
RE2: J2.9, U2.27 (RE2/CCP5/AN7)
RE: U2.11 (AN9/C12IN2-/CTED2/RB3), U7.2 (~RE), U7.3 (DE)
SCK: U2.38 (RD0/SCL2/SCK2/AN20), U6.14 (SCK)
SI: U2.2 (RD4/P2D/SDO2/AN24), U6.16 (SI)
SO: U2.39 (RD1/SDI1/SDA2/AN21), U6.17 (SO)
UART2RX: U2.5 (RD7/RX2/DT2/P1D/AN27), U7.1 (RO)
UART2TX: U2.4 (RD6/TX2/CK2/P1C/AN26), U7.4 (DI)
UART_RX: U2.44 (RC6/TX1/CK1/AN18), U4.1 (RXD)
UART_TX: U2.1 (RC7/RX1/DT1/AN19), U4.17 (TXD)
VBUS: C1.1, C2.1, C12.1, C14.1, C16.1, D1.1 (K), FB1.1, J4.6, J6.6, R8.1, R24.1, R25.1, TP1.1, U4.12 (VCC), U5.3 (VI)

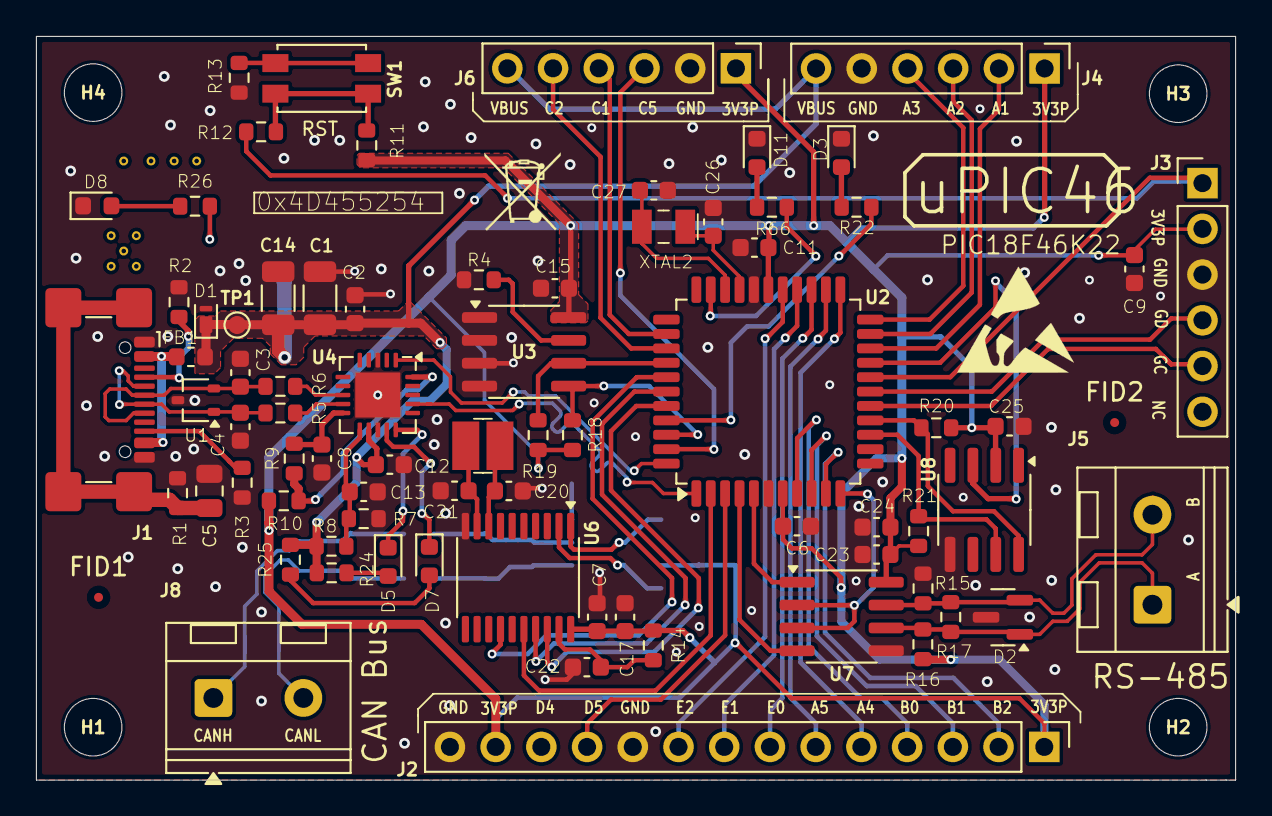
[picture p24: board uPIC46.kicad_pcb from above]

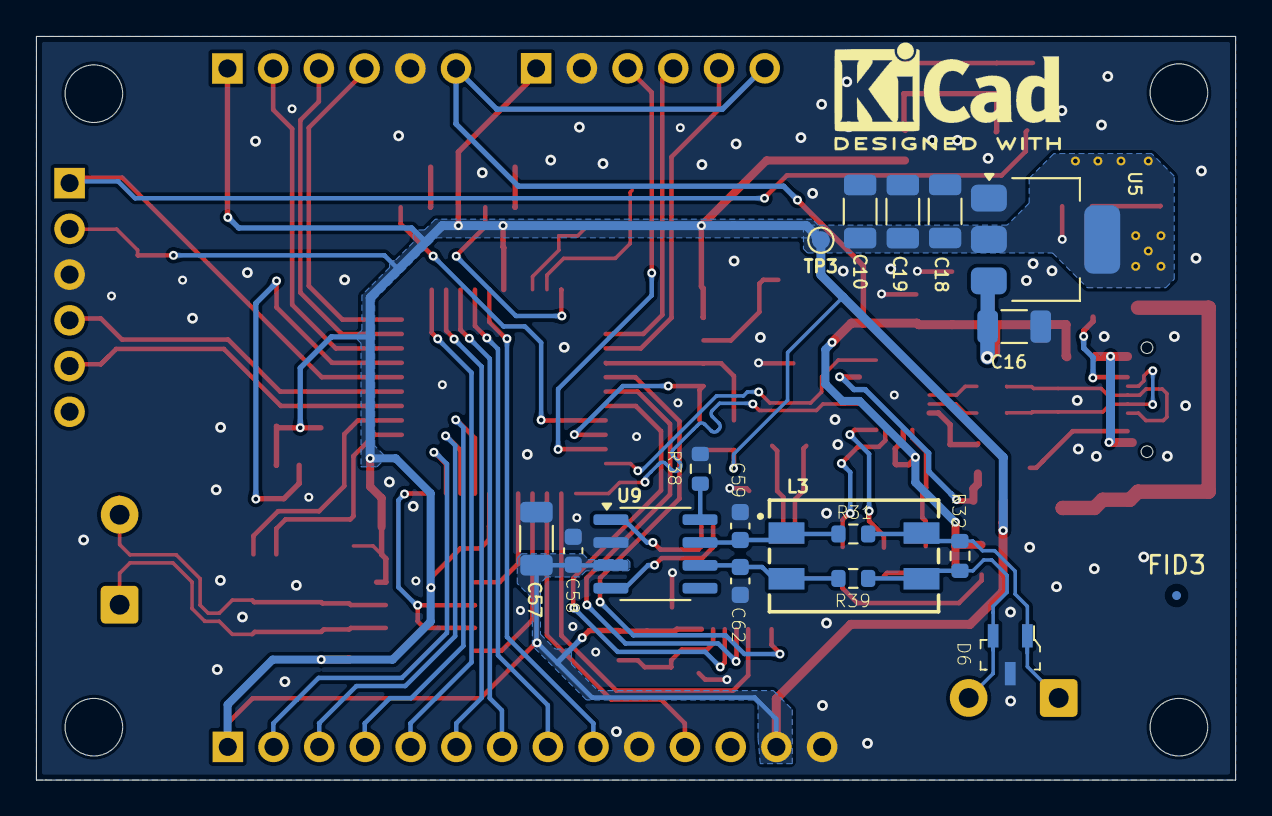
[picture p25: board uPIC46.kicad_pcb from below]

Board: 2 copper layers, 66.6 x 41.3 mm, 99 parts (18 on the bottom side), 72 nets.

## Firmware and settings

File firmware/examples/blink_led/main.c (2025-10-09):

#include "../config_bits.h"
#include <xc.h>
#include <stdint.h>
#define _XTAL_FREQ 8000000UL

// Pin mapping (uPIC46)
#define LED1_LAT LATCbits.LATC0
#define LED1_TRIS TRISCbits.TRISC0
#define LED2_LAT LATDbits.LATD3
#define LED2_TRIS TRISDbits.TRISD3

int main(void){
    // Make sure analogs disabled on ports used
    ANSELC = 0; ANSELD = 0; ANSELB = 0;
    LED1_TRIS = 0; // output
    LED2_TRIS = 0; // output
    LED1_LAT = 0;
    LED2_LAT = 0;
    while(1){
        LED1_LAT = 1;
        __delay_ms(250);
        LED1_LAT = 0;
        LED2_LAT = 1;
        __delay_ms(250);
        LED2_LAT = 0;
        __delay_ms(250);
    }
    return 0;
}

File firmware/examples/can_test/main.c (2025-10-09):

#include "../config_bits.h"
#include <xc.h>
#include <stdint.h>
#include "../Inc/uart_common.h"
#define _XTAL_FREQ 8000000UL

// SPI bit-bang pins for MCP2515
#define SPI_SCK_LAT LATDbits.LATD0
#define SPI_SCK_TRIS TRISDbits.TRISD0
#define SPI_MOSI_LAT LATDbits.LATD4
#define SPI_MOSI_TRIS TRISDbits.TRISD4
#define SPI_MISO_PORT PORTDbits.RD1
#define SPI_MISO_TRIS TRISDbits.TRISD1
#define SPI_CS_LAT LATDbits.LATD2
#define SPI_CS_TRIS TRISDbits.TRISD2

static inline void spi_init(void){
    ANSELD = 0; // digital
    SPI_SCK_TRIS = 0; SPI_MOSI_TRIS = 0; SPI_MISO_TRIS = 1; SPI_CS_TRIS = 0;
    SPI_CS_LAT = 1; SPI_SCK_LAT = 0; SPI_MOSI_LAT = 0;
}
void spi_delay(void){ __delay_us(2); }
uint8_t spi_transfer(uint8_t out){
    uint8_t in = 0;
    for(int i=0;i<8;i++){
        SPI_MOSI_LAT = (out & 0x80) ? 1 : 0;
        out <<= 1;
        spi_delay();
        SPI_SCK_LAT = 1; spi_delay();
        in <<= 1;
        if(SPI_MISO_PORT) in |= 1;
        SPI_SCK_LAT = 0; spi_delay();
    }
    return in;
}

// MCP2515 commands
#define MCP_RESET 0xC0
#define MCP_READ  0x03
#define MCP_WRITE 0x02
#define MCP_BITMOD 0x05
#define MCP_READ_STATUS 0xA0

void mcp_cs_low(){ SPI_CS_LAT = 0; __delay_us(1); }
void mcp_cs_high(){ SPI_CS_LAT = 1; __delay_us(1); }

void mcp_reset(void){
    mcp_cs_low();
    spi_transfer(MCP_RESET);
    mcp_cs_high();
    __delay_ms(10);
}
uint8_t mcp_read(uint8_t addr){
    uint8_t v;
    mcp_cs_low();
    spi_transfer(MCP_READ);
    spi_transfer(addr);
    v = spi_transfer(0);
    mcp_cs_high();
    return v;
}
void mcp_write(uint8_t addr, uint8_t val){
    mcp_cs_low();
    spi_transfer(MCP_WRITE);
    spi_transfer(addr);
    spi_transfer(val);
    mcp_cs_high();
}
void mcp_bitmod(uint8_t addr, uint8_t mask, uint8_t data){
    mcp_cs_low();
    spi_transfer(MCP_BITMOD);
    spi_transfer(addr);
    spi_transfer(mask);
    spi_transfer(data);
    mcp_cs_high();
}
uint8_t mcp_read_status(void){
    uint8_t v;
    mcp_cs_low();
    spi_transfer(MCP_READ_STATUS);
    v = spi_transfer(0);
    mcp_cs_high();
    return v;
}

int main(void){
    ANSELD = 0; ANSELB=0; ANSELC=0;
    uart_init();
    uart_puts("uPIC46 MCP2515 basic test\r\n");
    spi_init();
    mcp_reset();
    uart_puts("MCP reset done, reading CANCTRL/CANSTAT...\r\n");
    // CANCTRL at 0x0F, set loopback REQOP = 010 using BIT MODIFY (mask 0xE0)
    mcp_bitmod(0x0F, 0xE0, 0x40);
    __delay_ms(10);
    uint8_t canctrl = mcp_read(0x0F);
    uint8_t canstat = mcp_read(0x0E); // CANSTAT is 0x0E typically
    uart_puts("CANCTRL=0x"); uart_puthex(canctrl); uart_puts(" CANSTAT=0x"); uart_puthex(canstat); uart_puts("\r\n");
    uint8_t status = mcp_read_status();
    uart_puts("MCP READ STATUS: 0x"); uart_puthex(status); uart_puts("\r\n");
    while(1) __delay_ms(1000);
    return 0;
}
